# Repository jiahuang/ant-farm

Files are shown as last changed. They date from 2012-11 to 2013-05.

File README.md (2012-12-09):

ant-farm
========

Fuse the bits to clock the Attiny at 8mHz

lfuse sets the 1mHz internal clock
hfuse sets brownout detector at 2.0v

```
avrdude -p attiny24 -P /dev/cu.usbmodemfd121 -c avrisp -b 19200 -U lfuse:w:0x62:m -U hfuse:w:0xd8:m -U efuse:w:0xff:m
```

check the port that the attiny is connected to ```ls -l /dev/cu.*```

Increment the UUID and stick on the code
```
python build.py; make all; avrdude -p attiny24 -P /dev/cu.usbmodemfd121 -c avrisp -b 19200 -U flash:w:ant.hex;
```

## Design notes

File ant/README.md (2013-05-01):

#Ant

##PCB Schematic
Ant PCB schematic

##Wiring diagram
Ant wiring diagram

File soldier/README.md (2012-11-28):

#Soldier. The verification and reprogramming bench for ants

runs off of an arduino uno

uses the following libraries:

* [RF24](https://github.com/maniacbug/RF24)

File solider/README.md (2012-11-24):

#Solider. The verification and reprogramming bench for ants

runs off of an arduino uno

uses the following libraries:

* [RF24](https://github.com/maniacbug/RF24)

Note: set the RF channel to 2 on the RF24 library since that's the frequency the Ant is set at. Line 387 in RF24.cpp should read: 

```
setChannel(2);
```

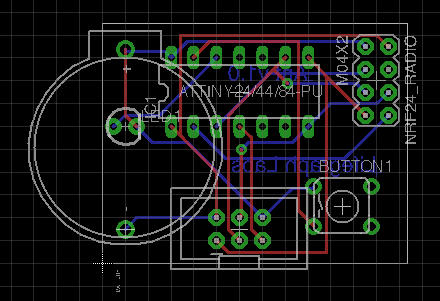
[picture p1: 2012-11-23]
ant/schematics/Ant-v1.png

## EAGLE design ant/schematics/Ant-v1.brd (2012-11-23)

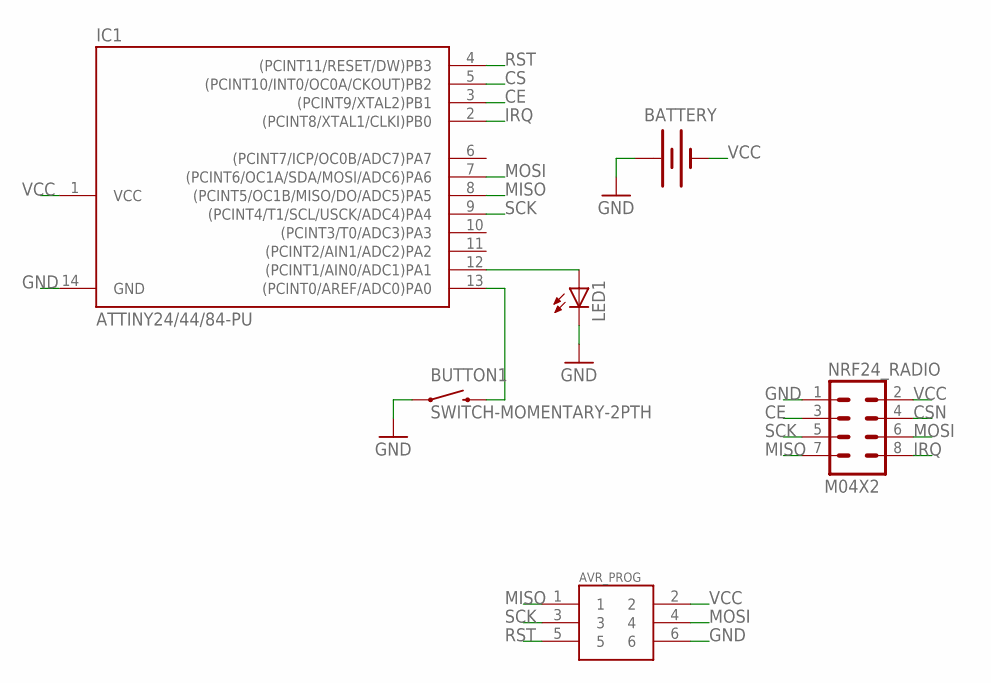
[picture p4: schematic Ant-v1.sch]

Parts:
AVR_PROG: M03X2; 2X3-SHROUDED
BATTERY: BATTERY20PTH; BATTCOM_20MM_PTH
BUTTON1: SWITCH-MOMENTARY-2PTH; TACTILE-PTH
IC1: ATTINY24/44/84-PU; DIL14
LED1: LED3MM
NRF24_RADIO: M04X2; 2X4

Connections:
CE: IC1.3 ((PCINT9/XTAL2)PB1), NRF24_RADIO.3
CS: IC1.5 ((PCINT10/INT0/OC0A/CKOUT)PB2)
CSN: NRF24_RADIO.4
GND: AVR_PROG.6, BATTERY.1 (+), BUTTON1.1, IC1.14 (GND), LED1.K (C), NRF24_RADIO.1
IRQ: IC1.2 ((PCINT8/XTAL1/CLKI)PB0), NRF24_RADIO.8
MISO: AVR_PROG.1, IC1.8 ((PCINT5/OC1B/MISO/DO/ADC5)PA5), NRF24_RADIO.7
MOSI: AVR_PROG.4, IC1.7 ((PCINT6/OC1A/SDA/MOSI/ADC6)PA6), NRF24_RADIO.6
unnamed: IC1.12 ((PCINT1/AIN0/ADC1)PA1), LED1.A
unnamed: BUTTON1.3 (2), IC1.13 ((PCINT0/AREF/ADC0)PA0)
RST: AVR_PROG.5, IC1.4 ((PCINT11/RESET/DW)PB3)
SCK: AVR_PROG.3, IC1.9 ((PCINT4/T1/SCL/USCK/ADC4)PA4), NRF24_RADIO.5
VCC: AVR_PROG.2, BATTERY.2 (-), IC1.1 (VCC), NRF24_RADIO.2

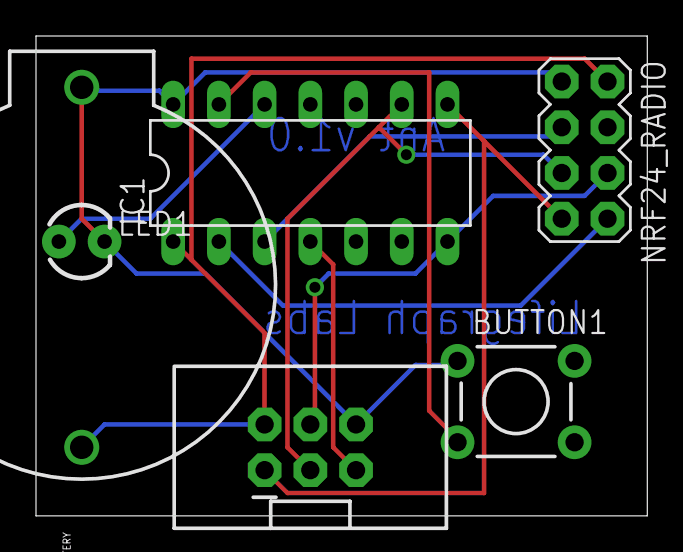
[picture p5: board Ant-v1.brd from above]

Board: 2 copper layers, 34.0 x 26.7 mm, 6 parts (0 on the bottom side), 10 nets.

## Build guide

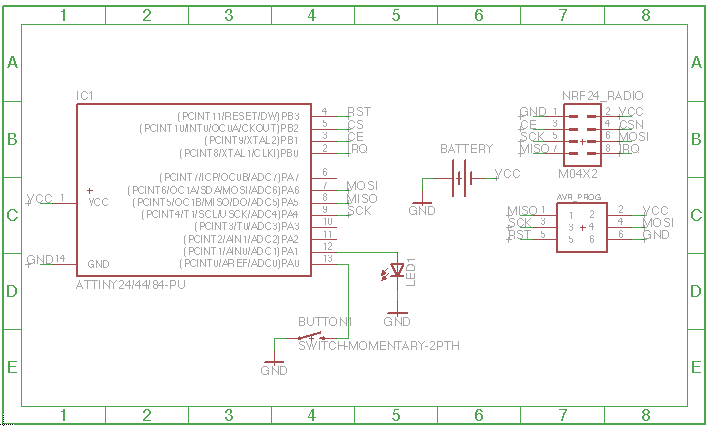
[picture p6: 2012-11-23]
ant/schematics/Ant-v1-wiring.png

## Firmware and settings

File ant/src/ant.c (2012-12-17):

#include <avr/io.h>
#include <avr/interrupt.h>
#include <avr/sleep.h>
#include <avr/wdt.h>
#include "id.c"

#define sbi(var, mask)   ((var) |= (uint8_t)(1 << mask))
#define cbi(var, mask)   ((var) &= (uint8_t)~(1 << mask))

#define UUID_SIZE  2
// The pin register associated with the nRF24 IRQ pin
#define NRF_IRQ 0

#define MINUTES_TO_RESET 5
// every 3 cycles of watchdog, pad a payload block with 0s
#define CYCLES_TO_PAD 3
// the size of each payload
#define PAYLOAD_SIZE 6

// The receiver frequency. Should match colony transmit frequency.
// Frequency = 2400 + RF_CH [MHz]
#define RECEIVE_FREQ 3 // RF_CH = 3
// The transmit frequency. Should match the queen receive frequency.
#define TRANSMIT_FREQ 10 // RF_CH = 10

//Define functions
//======================
void ioinit(void);      //Initializes IO
void delay_ms(uint16_t x); //General purpose delay
void delay_us(uint8_t x);
uint8_t ping_pong(void);
void pong(void);

// TX address. RX address needs to be the same as this
// goes from least significant to most significant
uint8_t data_pipe[5] = {0xE7, 0xE7, 0xE7, 0xE7, 0xE7};
// 2 for ant, 2 for colony, 2 for ping #
// can hold up to 6 payloads at once. 
// real amount of payloads we use before we ping is randomized
uint8_t data_array[30] = {
  0x00, 0x00, 0x00, 0x00, 0x00, 0x00,
  0x00, 0x00, 0x00, 0x00, 0x00, 0x00,
  0x00, 0x00, 0x00, 0x00, 0x00, 0x00, 
  0x00, 0x00, 0x00, 0x00, 0x00, 0x00,
  0x00, 0x00, 0x00, 0x00, 0x00, 0x00
  };

uint8_t current_payload = 0;
uint8_t current_cycle = 0;

// payload size of 8 for the colony, but only 2 are used
uint8_t data_received[8] = {0x00, 0x00, 0x00, 0x00, 0x00, 0x00, 0x00, 0x00};

char UUID[UUID_SIZE] = { ID_1, ID_2 } ;
// ~8 resets per minute to get total number of resets
uint16_t interrupts_remaining = 8 * MINUTES_TO_RESET;

uint16_t ping_id = 0x00;

#include "nRF24L01-tx.c"
#include "nRF24L01-rx.c"

//======================
ISR(PCINT1_vect)
{
  cli();
  PORTA = PORTA ^ (1 << 3);
  
  while( ping_pong() & 0x40) { }
  sei();
}

ISR(WDT_vect) {

    cli();
    PORTA = PORTA ^ (1<<2 ); // flash an LED
    tx_send_command(0x27, (1 << RX_DR) | (1 << TX_DS) | (1 << MAX_RT));

    // pad with PAYLOAD_SIZE bytes
    for(int i = 0; i < PAYLOAD_SIZE; i++) {
      data_array[current_payload*PAYLOAD_SIZE + i] = 0x00;
    }
    current_payload++;

    // check to see if we've hit max payload and transmit
    pong();
    
    if (--interrupts_remaining <= 0) {

      configure_receiver(data_pipe, RECEIVE_FREQ);

      delay_ms(20);
      
      interrupts_remaining = 8 * MINUTES_TO_RESET;

    }
    sei();
}

void pong(void)
{
  // delay_ms(100);
  // PORTA = PORTA ^(1 << 3);
  if (current_payload >= MAX_PAYLOAD) {
  // get ready to pong back a message
    configure_transmitter(data_pipe, TRANSMIT_FREQ);

    // delay some more for randomness
    delay_ms(MS_DELAY * 25 + 10); // space out at at least 25 ms
    // delay_ms((UUID[0] * 1000) & 255);
    
    // Send over the ping
    transmit_data(data_array);
    // // wait for transmitting to be done
    delay_ms(5);

    PORTA = PORTA ^ (1<<LED ); // flash an LED
    delay_ms(2);
    // go back to receiving
    configure_receiver(data_pipe, RECEIVE_FREQ);
    // delay for some fun
    delay_ms(5);
    PORTA = PORTA ^ (1<<LED ); // flash an LED

    // reset everything
    current_payload = 0 ;

  }
}

uint8_t ping_pong(void) 
{
  
  uint8_t incoming = 0;
  incoming = tx_send_byte(0xFF); //Get status register
  if (incoming & 0x40)
  {

    //We have data!
    receive_data(data_received, sizeof(data_received));

    // append to payload
    data_array[current_payload*PAYLOAD_SIZE] = data_received[0];
    data_array[current_payload*PAYLOAD_SIZE+1] = data_received[1];
    data_array[current_payload*PAYLOAD_SIZE+2] = UUID[0];
    data_array[current_payload*PAYLOAD_SIZE+3] = UUID[1];
    data_array[current_payload*PAYLOAD_SIZE+4] = ((ping_id >> 8) & 0xFF);
    data_array[current_payload*PAYLOAD_SIZE+5] = (ping_id & 0xFF);

    if (ping_id == 0xFFFF) ping_id = 0;
    else ping_id++;

    current_payload++;
    pong();
  }

  // delay_ms(100);
  return incoming;
}

int main (void)
{  
  // Set up all the input and output ports
  ioinit();

  // Turn off the led when it's loaded
  PORTA = PORTA & ~(1 << LED);

  ACSR = (1<<ACD); //Turn off Analog Comparator - this removes about 1uA

  PRR = 0x0B; //Reduce everything except timer0
    
  while(1)
  {
   sleep_cpu(); //Sleep until a ping wakes us up on interrupt
  }
  
  return(0);
}

void ioinit (void)
{
  cli();
  //1 = Output, 0 = Input
  DDRA = 0xFF & ~(1<<TX_MISO);
  DDRB = 0b00000110; //(CE on PB1) (CS on PB2)

  PORTA = 0b10010010;

  /* Clear WDRF in MCUSR */
  MCUSR = 0x00;
  /* Write logical one to WDCE and WDE */ 
  WDTCSR |= (1 << WDCE) | (1 << WDE);
  /* Turn off WDT */
  WDTCSR = 0x00;

  cbi(PORTB, TX_CE); //Stand by mode
  
  //Init Timer0 for delay_us
  TCCR0B = (1<<CS00); //Set Prescaler to No Prescaling (assume we are running at internal 1MHz). CS00=1 

  configure_receiver(data_pipe, RECEIVE_FREQ);

  GIFR = (1 << PCIF1); // Enable logic interrupt on PCINT 11:8
  GIMSK = (1 << PCIE1); // Enable pin change interrupt request on PCINT 11:8
  PCMSK1 = (1 << NRF_IRQ); 
  MCUCR = (1<<SM1)|(1<<SE); //Setup Power-down mode and enable sleep

  //prescaler set to 8 seconds
  WDTCSR |= (1 << WDCE) | (1 << WDP3) |  (1 << WDP0);

  // Set the watchdog to interrupt instead of reset
  WDTCSR |= (1 << WDIE);
  
  sei(); //Enable interrupts
}

//General short delays
void delay_ms(uint16_t x)
{
  for (; x > 0 ; x--)
  {
    delay_us(250);
    delay_us(250);
    delay_us(250);
    delay_us(250);
  }
}

//General short delays
void delay_us(uint8_t x)
{
  TIFR0 = 0x01; //Clear any interrupt flags on Timer2
  
    TCNT0 = 256 - x; //256 - 125 = 131 : Preload timer 2 for x clicks. Should be 1us per click

  while( (TIFR0 & (1<<TOV0)) == 0);
}

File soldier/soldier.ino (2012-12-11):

// modified from RF24's getting started example

#include <SPI.h>
#include "nRF24L01.h"
#include "RF24.h"
#include "printf.h"

//
// Hardware configuration
//

// Set up nRF24L01 radio on SPI bus plus pins 9 & 10 

RF24 radio(9,10);

int TRANSMIT_TIME = 30000;//65535;
int MULTIPLE = 5;
int transmit_time_counter = 0;
int multiple_counter = 0;
//
// Topology
//

// Open a reading address. This address needs to match the address that the ant is transmitting at
const uint64_t pipes[1] = { 0xE7E7E7E7E7LL };

void setup(void)
{

  Serial.begin(57600);
  printf_begin();
  printf("\n\rsoldier\n\r");
  printf("ROLE: Receiver\n\r");

  // Setup and configure rf radio
  Serial.println("Hey");
  radio.begin();
  Serial.println("It has begined");
  radio.setChannel(10);
  radio.setPayloadSize(8);
  radio.setAutoAck(false);
  radio.setCRCLength(RF24_CRC_8);
  radio.setRetries(15,15);
  radio.setPALevel(RF24_PA_MIN);
  
  // optionally, increase the delay between retries & # of retries
//  radio.setRetries(15,15);
  // radio.setPALevel(RF24_PA_MID);
//  radio.setDataRate(RF24_250KBPS);
  // optionally, reduce the payload size.  seems to
  // improve reliability
  // radio.setPayloadSize(8);

  // read at the pipe
//  radio.openReadingPipe(0,pipes[0]);
  radio.openReadingPipe(1,0xE7E7E7E7E7LL);
  radio.openWritingPipe(0xE7E7E7E7E7LL);
 
  transmit_init();
  Serial.println("Here comes the details");
  radio.printDetails();
  Serial.println("hey all done here");
}

void receive_init() {
  radio.startListening();
}

void transmit_init() {
  radio.stopListening();
}

void loop(void)
{
  // if there is data ready
  //printf("" + radio.available());
  if (transmit_time_counter >= TRANSMIT_TIME) {
    transmit_init();
//    delay(200);
      byte queen_id[8] = {30,30,30,30, 0, 0, 0, 0};
      boolean okay = transmit(queen_id);
      if (okay) {
       transmit_time_counter = 0;
       receive_init();
//       delay(200);
      } else {
       Serial.println("OOOOHHHH NOOOO"); 
      }
  } else {
    if (multiple_counter >= MULTIPLE) {
      multiple_counter = 0;
      transmit_time_counter++;
    } else {
      multiple_counter++;
    }
    receive_data();
  }
    
}

boolean transmit(byte * data) {
  
  boolean okay = radio.write(data, 8);
  if (okay) {
    Serial.println("Serial transmit okay");
  } else {
   Serial.println("PROLLEM WITH TRANSMIT"); 
  }
  return okay;
}

void receive_data(void) {
 if ( radio.available() )
  {
    // Dump the payloads until we've gotten everything
    byte received_data[8];
    bool done = false;
    while (!done)
    {
      done = radio.read( &received_data, 8 );
      
      // check that it's a queen
      if ( (received_data[4] | received_data[5] | 
        received_data[6] | received_data[7]) != 0x0) {
        Serial.print("Got payload: ");
        for (int i = 0; i < 8; i++) {
          if (received_data[i] <= 0xF)
            Serial.print("0");
          Serial.print(received_data[i], HEX); 
        }
        Serial.println();
      }
      
      // Delay just a little bit to let the other unit
      // make the transition to receiver
      delay(20);
    } 
  }
}

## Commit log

2012-11-23 added ant schematics
    [Ant-v1.brd, Ant-v1.sch]
2012-11-23 added auth token for wiring diagram
2012-11-29 got button flash working
2012-11-30 reducing power consumption on the ant
2012-12-03 fuse for brownout detection
2012-12-06 adding IRQ to the IRQ pin
2012-12-06 adding another LED. Switched Analog voltage to pin 3
2012-12-07 bumped up transmit power
2012-12-07 Switched from Analog Voltage UUID to build scripts :(
2012-12-08 Fixed the sleep code and updated the correct fuses
    [ant.c]
2012-12-08 BOD Fuse bit set to 2.0V instead of 1.8V to protect the nRF24
2012-12-09 updating readme to 2v BOD
2012-12-09 Added watchdog timer to reset
    [ant.c]
2012-12-09 Fixed watchdog code to run every 8 seconds instead of 2
    [ant.c]
2012-12-09 switching led blinking to not be during transmission
2012-12-10 Added more flushing code and set the tranceiver to receive on reset
    [ant.c, nRF24L01-rx.c, nRF24L01-tx.c]
2012-12-11 Added a delay to the WD interrupt
2012-12-15 Fixed a bug on the sign up page
    [colony.c]
2012-12-16 updaing queen listener to behave correctly
    [ant.c, queen_listener.py]
2012-12-16 my queen listener pings correctly
    [queen_listener.py]

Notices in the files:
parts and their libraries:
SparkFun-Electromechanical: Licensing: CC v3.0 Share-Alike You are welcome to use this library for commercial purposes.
